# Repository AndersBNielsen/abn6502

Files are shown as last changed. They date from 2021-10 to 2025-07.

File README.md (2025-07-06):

# ABNielsen.com 6502 Single Board Computer Revision 2

This is a 6502-based complete single board computer intended to help during the global IC shortage. Why use new chips when you can reuse scrap?

## Update Update! The newest ABN6502 SBC R2 board is available as:
- Blank PCBs 
- Fully mounted PCBs including sockets and headers
- Kits with SMD components presoldered, limiting soldering to though hole components/sockets. 

All gold plated (ENIG) PCBs: https://www.imania.dk/index.php?currency=EUR&cPath=204&sort=5a&language=en

Coming soon: R2 video. 

Complete hardware overview of R1:

<a href="http://www.youtube.com/watch?feature=player_embedded&v=w5cA64xof2I" target="_blank">
 Watch the video
</a>

Video about the wireless bootloader:

<a href="http://www.youtube.com/watch?feature=player_embedded&v=NABU7gQDtcs" target="_blank">
 Watch the video
</a>

Check out the NEW project on HackADay if you want to read more and see some pretty pictures :)

https://hackaday.io/project/184725-abn6502-sbc-r1

For R1 I got rid of the Padauk MCU without increasing the chip count!

# Build instructions:

1) Send gerber files from /hardware to your favorite board house (see "Getting a PCB" below) (or get a board from [my store](https://www.imania.dk/index.php?currency=EUR&cPath=204&sort=5a&language=en)) 
2) Build the firmware using assemble.sh (macOS/Linux) - this will also try to burn the main ROM using Minipro. Dependencies: [CC65] (https://github.com/cc65/cc65) and a way to burn the ROM's.
3) Source the IC's - the spirit of this project is to contribute as little as possible to the global IC shortage and get used chips locally or from Ebay/AliExpress/etc.
4) Burn the ROMs. I use a TL866II Plus variant for the actual ROMs.
5) Solder away. If you can solder 0805 components(poorly), you should be fine. Some optional components (the microUSB connector, the 3v3 regulator, and the RF-module) require a bit more skill.  
6) For the PS/2-keyboard I use the 6522's Shift Register, PB6, and a 74xx74 flip flop.  See my R1 Hardware overview at 7:46: https://youtu.be/w5cA64xof2I?t=466 This is now included on the board - instead of a PS/2 connector which can be harder to source I went with a USB-A-connector. Keyboard plugs straight into the board. 
7) Enjoy!

Optional:
Setup SSH keys with a Raspberry Pi, connect an nRF24L01+ compatible module to it and compile the wireless bootloader code in /software_linux

Also optional:
Microsoft BASIC can be enabled by cloning the msbasic Github repo into the same folder you cloned this repo.

> git clone https://github.com/mist64/msbasic.git

Then uncomment ;BASIC := 1 (Remove the ";") and run assemble.sh - this will let you run BASIC by pressing F4.
To change settings for BASIC, values can be changed in defines_abn6502.s

Also, please note that the current code assumes VRAM starts at $0800 rather than the default $2000 in the schematic - resistors will have pads for configuring in the next build, but for now it requires jumpers.

License: Attribution-NonCommercial 4.0 International (CC BY-NC 4.0) https://creativecommons.org/licenses/by-nc/4.0/

## Getting a PCB
This project is kindly sponsored by JLCPCB. They offer cheap, professional looking PCBs and super fast delivery.

Step 1: Get the gerber file zip package from the /hardware/jlc folder
[hardware/jlcpcb/production_files/GERBER-6502.zip](hardware/jlcpcb/production_files/GERBER-6502.zip) for instance.

Step 2: Upload to JLCPCB [https://jlcpcb.com/?from=Anders_N](https://jlcpcb.com/?from=Anders_N)

Upload

Step 3: Pick your color, surface finish and order.

Select settings

Save your choice

You can use these affiliate links to get a board for $2 and also get $54 worth of New User Coupons at: https://jlcpcb.com/?from=Anders_N

And in case you also want to order a 3D-printed case you can use this link. 
How to Get a $7 3D Printing Coupon: [https://3d.jlcpcb.com/?from=Anders3DP](https://jlc3dp.com/?from=Anders_N)

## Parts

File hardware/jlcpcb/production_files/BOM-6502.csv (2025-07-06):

Comment | Designator | Footprint | LCSC | Quantity
2k2 | R14,R17,R22,R23,R24,R25 | R_0805_2012Metric | C114561 | 6
220uF | C12 | CP_Elec_6.3x7.7 | C131120 | 1
16Mhz | Y2 | Crystal_SMD_3225-4Pin_3.2x2.5mm | C13738 | 1
SST39SF010 | U5 | DIP_Socket-32_W11.9_W12.7_W15.24_W17.78_W18.5_3M_232-1285-00-0602J | C146583 | 1
100nF | C10,C11,C15,C16,C17,C18,C19,C23,C24,C25,C3,C4,C5,C6,C7,C8,C9 | C_0603_1608Metric | C14663 | 17
10uF | C22 | C_0805_2012Metric | C15850 | 1
150k | R12 | R_0805_2012Metric | C17470 | 1
150 | R7 | R_0805_2012Metric | C17471 | 1
1M | R5 | R_0805_2012Metric | C17514 | 1
3k | R1,R10,R11,R2,R3,R4,R50,R51,R52,R53,R54,R55,R56,R57,R8,R9 | R_0805_2012Metric | C17661 | 16
470 | R6 | R_0805_2012Metric | C17710 | 1
74HC14 | U1,U13,U14,U17,U21,U8 | DIP-14_W7.62mm | C2325 | 6
Interface | J20 | PinHeader_2x05_P2.54mm_Vertical | C2685204 | 1
1uF | C13,C14,C20,C21 | C_0805_2012Metric | C28323 | 4
USB2.0_16P | J9 | USB_C_Receptacle_HCTL_HC-TYPE-C-16P-01A | C2894897 | 1
5k1 | R58,R59 | R_0805_2012Metric | C3016714 | 2
MIC5504-3.3YM5 | U15 | SOT-23-5 | C3021093 | 1
Address bus | J16 | PinHeader_2x08_P2.54mm_Vertical | C30734 | 1
SW_Push | SW1 | SW_SPST_TL3342 | C318884 | 1
USB_A | J17 | USB_A_Molex_67643_Horizontal | C456018 | 1
14pF | C1,C2 | C_0805_2012Metric | C519919 | 2
DB15_Female_HighDensity | J6 | DSUB-15-HD_Female_Horizontal_P2.29x1.98mm_EdgePinOffset8.35mm_Housed_MountingHolesOffset10.89mm | C711363 | 1
74HC109 | U12,U19,U20,U6,U7 | DIP-16_W7.62mm | C72115 | 5
74HC245 | U10,U11,U4 | DIP-20_W7.62mm | C72118 | 3
62256 | U16,U18 | DIP-28_W15.24mm | C72121 | 2
R6502 | U2,U3 | DIP-40_W15.24mm | C72123 | 2
CA | J3,J4 | PinHeader_1x02_P2.54mm_Vertical | C7499322 | 2
PORTAB | J2 | PinHeader_1x16_P2.54mm_Vertical | C7500783 | 1
3v3 | 3v3,5V0,DCTRL3,DCTRL4,DCTRL5,DCTRL6,DCTRL7,DVB0,DVB1,DVEN1 | LED_0805_2012Metric | C84256 | 10
Power | J14 | PinHeader_2x06_P2.54mm_Vertical | C92269 | 1
Data_bus | J15 | PinHeader_2x04_P2.54mm_Vertical | C92271 | 1
W27c512? | J5 | PinHeader_1x02_P2.54mm_Vertical |  | 1
Control_bus | J12 | PinHeader_1x08_P2.54mm_Vertical |  | 1
GPCO | J11 | PinHeader_1x05_P2.54mm_Vertical |  | 1
16Mhz |  | Crystal_HC49-U_Vertical |  | 0
Conn_01x12_Male |  | PinHeader_1x12_P2.54mm_Vertical |  | 0
USB | J10 | PinHeader_1x02_P2.54mm_Vertical |  | 1
5V | J1 | PinHeader_1x02_P2.54mm_Vertical |  | 1
NC | R30 | SolderJumper-2_P1.3mm_Open_RoundedPad1.0x1.5mm |  | 1
5V | J8 | PinHeader_1x02_P2.54mm_Vertical |  | 1
NC |  | R_0805_2012Metric |  | 0
NC | R36 | SolderJumper-2_P1.3mm_Open_RoundedPad1.0x1.5mm |  | 1
NC | C34 | C_0805_2012Metric |  | 1
NC | R32 | SolderJumper-2_P1.3mm_Open_RoundedPad1.0x1.5mm |  | 1
NC |  | R_0805_2012Metric |  | 0
NC | C32 | C_0805_2012Metric |  | 1
NC | R31 | SolderJumper-2_P1.3mm_Open_RoundedPad1.0x1.5mm |  | 1
NC | R39 | SolderJumper-2_P1.3mm_Open_RoundedPad1.0x1.5mm |  | 1
NC | C29 | C_0805_2012Metric |  | 1
NC | R49 | R_0805_2012Metric |  | 1
NC | C30 | C_0805_2012Metric |  | 1
NC | R44 | SolderJumper-2_P1.3mm_Open_RoundedPad1.0x1.5mm |  | 1
NC | C27 | C_0805_2012Metric |  | 1
NRF24L01_Breakout | U9 | NRF24L01-SMD |  | 1
NC | C33 | C_0805_2012Metric |  | 1
NC |  | R_0805_2012Metric |  | 0
NC | C28 | C_0805_2012Metric |  | 1
NC | R34 | SolderJumper-2_P1.3mm_Open_RoundedPad1.0x1.5mm |  | 1
NC | R29 | SolderJumper-2_P1.3mm_Open_RoundedPad1.0x1.5mm |  | 1
NC | R47 | SolderJumper-2_P1.3mm_Open_RoundedPad1.0x1.5mm |  | 1
NC | R33 | SolderJumper-2_P1.3mm_Open_RoundedPad1.0x1.5mm |  | 1
NC | R37 | SolderJumper-2_P1.3mm_Open_RoundedPad1.0x1.5mm |  | 1
NC | R43 | SolderJumper-2_P1.3mm_Open_RoundedPad1.0x1.5mm |  | 1
NC |  | R_0805_2012Metric |  | 0
NC | R35 | SolderJumper-2_P1.3mm_Open_RoundedPad1.0x1.5mm |  | 1
NC | C35 | C_0805_2012Metric |  | 1
NC | R45 | SolderJumper-2_P1.3mm_Open_RoundedPad1.0x1.5mm |  | 1
NC | C31 | C_0805_2012Metric |  | 1
NC | R42 | SolderJumper-2_P1.3mm_Open_RoundedPad1.0x1.5mm |  | 1
NC | R46 | SolderJumper-2_P1.3mm_Open_RoundedPad1.0x1.5mm |  | 1
NC | C36 | C_0805_2012Metric |  | 1
NC | R38 | SolderJumper-2_P1.3mm_Open_RoundedPad1.0x1.5mm |  | 1
NC | C37 | C_0805_2012Metric |  | 1
NC | R41 | SolderJumper-2_P1.3mm_Open_RoundedPad1.0x1.5mm |  | 1
NC | C26 | C_0805_2012Metric |  | 1
NC | R40 | SolderJumper-2_P1.3mm_Open_RoundedPad1.0x1.5mm |  | 1

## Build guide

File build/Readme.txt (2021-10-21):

This folder is where the build output goes for ROMs

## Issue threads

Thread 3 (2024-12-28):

Questions About VGA - Custom Build Help

vslinuxdotnet, 2024-12-28:
Hello dear Anders,

I build this board in dev PCB board but no output video was displayed in my old LCD.
The board seams working e have first debug led ON means CE in 74ls165 LOW, so chip IC enable correct ?
I have VSYNC (36Hz+-) and HSYNC (51Hz+-) signals not very stable, Green about 2Mhz wave form, is ok ?
You say in video the resolution is 512x512, this will only work in old CRT or can also work with old year 2000 small LCD ?
What test can i do the check if the board in not freezed ?

Thank You,

VS

AndersBNielsen, 2024-12-28:
Do you have the VRAM configured on the back of the board and does it match
the address defined in code?
The resolution is a bit odd - 400x240 and you can’t be sure the monitor
will register that.
If you have a modern monitor it should register it as 800x480 - if you have
an older flat panel you might need to crop in software to 640x480 (just
don’t write to edges of the screen framebuffer).

Do *not* connect a CRT unless you have verified yourself that it’s safe for
your CRT (I wouldn’t recommend it)

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

vslinuxdotnet, 2024-12-28:
I have the resistors configured like your diagram, what is the address $4000 ?
the resistors that change that is R18,R19,R20,R21 ?
1=HIGH,0=LOW, so 1000 = $4000
Can explain a like more :) ?
In your code:
SCREENSTARTH = $08 ; Change this to the page your Video RAM starts! (VRAM at $0800 requires a few jumpers to change from the default $2000 - this will change in the next build of R1)

So i have it in wrong address ?

> Do you have the VRAM configured on the back of the board and does it match the address defined in code? The resolution is a bit odd - 400x240 and you can’t be sure the monitor will register that. If you have a modern monitor it should register it as 800x480 - if you have an older flat panel you might need to crop in software to 640x480 (just don’t write to edges of the screen framebuffer). Do *not* connect a CRT unless you have verified yourself that it’s safe for your CRT (I wouldn’t recommend it)
> […](#)
> On Sat, Dec 28, 2024 at 20.17 Vasco Santos ***@***.***> wrote: Hello dear Anders, I build this board in dev PCB board but no output video was displayed in my old LCD. The board seams working e have first debug led ON means CE in 74ls165 LOW, so chip IC enable correct ? I have VSYNC (37Hz+-) and HSYNC (60Hz+-) signals, Green about 2Mhz wave form, is ok ? You say in video the resolution is 512x512, this will only work in old CRT or can also work with old year 2000 small LCD ? What test can I do the check if the board in not freezed or something like that. Thank You, VS — Reply to this email directly, view it on GitHub <#3>, or unsubscribe <https://github.com/notifications/unsubscribe-auth/AB2SHITVAITFTI2MB2IQIR32H3TK3AVCNFSM6AAAAABUKALTVKVHI2DSMVQWIX3LMV43ASLTON2WKOZSG43DCOBSGQ2DMMQ> . You are receiving this because you are subscribed to this thread.Message ID: ***@***.***>

vslinuxdotnet, 2024-12-29:
No luck to get it working, check all IC's checked wires and no luck, must debug it by serial or a led blink.
I found a interesting thing about the 74hc04A that pass from 10ma to 60ma, and get gets hot or more just by touch in pins.

The beast:

vslinuxdotnet, 2025-01-03:
Sorry for bothering you about this, but can you help ?
Thanks

AndersBNielsen, 2025-01-04:
Absolutely! I haven’t had too much time over the holidays but that should
change soon.

I found a bug that the 74’161 must be a 74LS161 and not a 74HC161 - not
sure if that could be affecting you?

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

vslinuxdotnet, 2025-01-04:
Hello, thanks for your time.
I have the LS version but I order the HC version :).
The problem is that I don't have the correct Vsync and Hsync, which seems Random at 30khz.
What is the correct value to put in VRam register?
In past two days in debug, meter wires and corrections with an oscilloscope and the board is alive all wires ok just no vga.
I also simulate with a Arduino to create the 60khz and 31.5khz and the monitor turns on without image.

Note: if you put some A17 jumper option to GND, and connect reset you will support more ROMS :)

A 4 de janeiro de 2025 07:44:12 WET, AndersBNielsen ***@***.***> escreveu:
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
--
Sent from my Android device with K-9 Mail. Please excuse my brevity.

AndersBNielsen, 2025-01-04:
Sounds like you have the correct VRAM resistors.
Regardless you should have a stable VSYNC and HSYNC - that part only relies
on the ‘590s and the bit of glue logic generating the syncs.
I suggest you check the inputs of the ‘109 JnK and if you don’t see
something reasonable trace back towards the 590s.

Another thing - Did you populate the reset circuit on the back?

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

vslinuxdotnet, 2025-01-04:
This circuit can generate Vsync and Hsync without CPU and ROM?
What is the correct VRAM address for the default resistors in your diagram?

A 4 de janeiro de 2025 09:23:18 WET, AndersBNielsen ***@***.***> escreveu:
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
--
Sent from my Android device with K-9 Mail. Please excuse my brevity.

AndersBNielsen, 2025-01-04:
The way it is in the schematic with only A11 pulled high and A12-14 pulled
low puts the VRAM base address at $0800

If the counters and U8, U17 and U12 are functioning correctly, you should
have sync signals.

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

vslinuxdotnet, 2025-01-04:
Ok, that's it, the counters without CPU, Ram or ROM will get the sync?

A 4 de janeiro de 2025 12:26:31 WET, AndersBNielsen ***@***.***> escreveu:
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
--
Sent from my Android device with K-9 Mail. Please excuse my brevity.

AndersBNielsen, 2025-01-04:
Yup. The counters just need the 2MHz from the ‘161.
It might be hard to get it going without a PCB though.

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

vslinuxdotnet, 2025-01-09:
Hello,
after some debug about 74hc590... I Detected  fakes IC's!
I tested the logic and works with low speed clock, but with 1Mhz or so they get completely malfunction, stops counting, reset it self.
I order new old stock arrived today and get some vsync and hsync finally!
But not the 31.5khz and 60.0khz needed, I get 31.25khz and 60.15khz, it's close... but not the correct frequency to turn on the screen.
I replace the 74hc109 and the 74hc32, tested with a 12mhz oscillator but get the same clock with this minimal error.
What can I do ?

Thanks

AndersBNielsen, 2025-01-10:
60Hz you mean :)

31.25KHz is less than 0.8% off - that should work. It could be it doesn't want to turn on because of random data on the rgb lines - you can try pulling RGB low instead of connecting them.

vslinuxdotnet, 2025-01-11:
Hello,
yes it 60Hz, any the SYNC error is acceptable, after some debug is finally working!!!
The main problem was the fakes 74hc590p.
This ones :
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

Then i tested in my 19" CRT with 25 years and don't work because R and B must be to GND or no picture available and not turn on.
But  in LCD's they don't care about R and B lines disconnected, they will turn on just with sync lines.

So if you what some considerations to do in your next revision:

  - U19 and U20 must be LS version or they don't work as expected.
  - U14 is recommended to be HCT version, with HC version, they can suck 200mA, gets hot and died at random time.
  - Red and Blue must be connected to GND or  some CRT's from the past may not work.
  - To support more Flash ROM's add a jumper to pin 30 to GND and pin 1 connect it to main RST.

Many thanks for your time.
Regards.

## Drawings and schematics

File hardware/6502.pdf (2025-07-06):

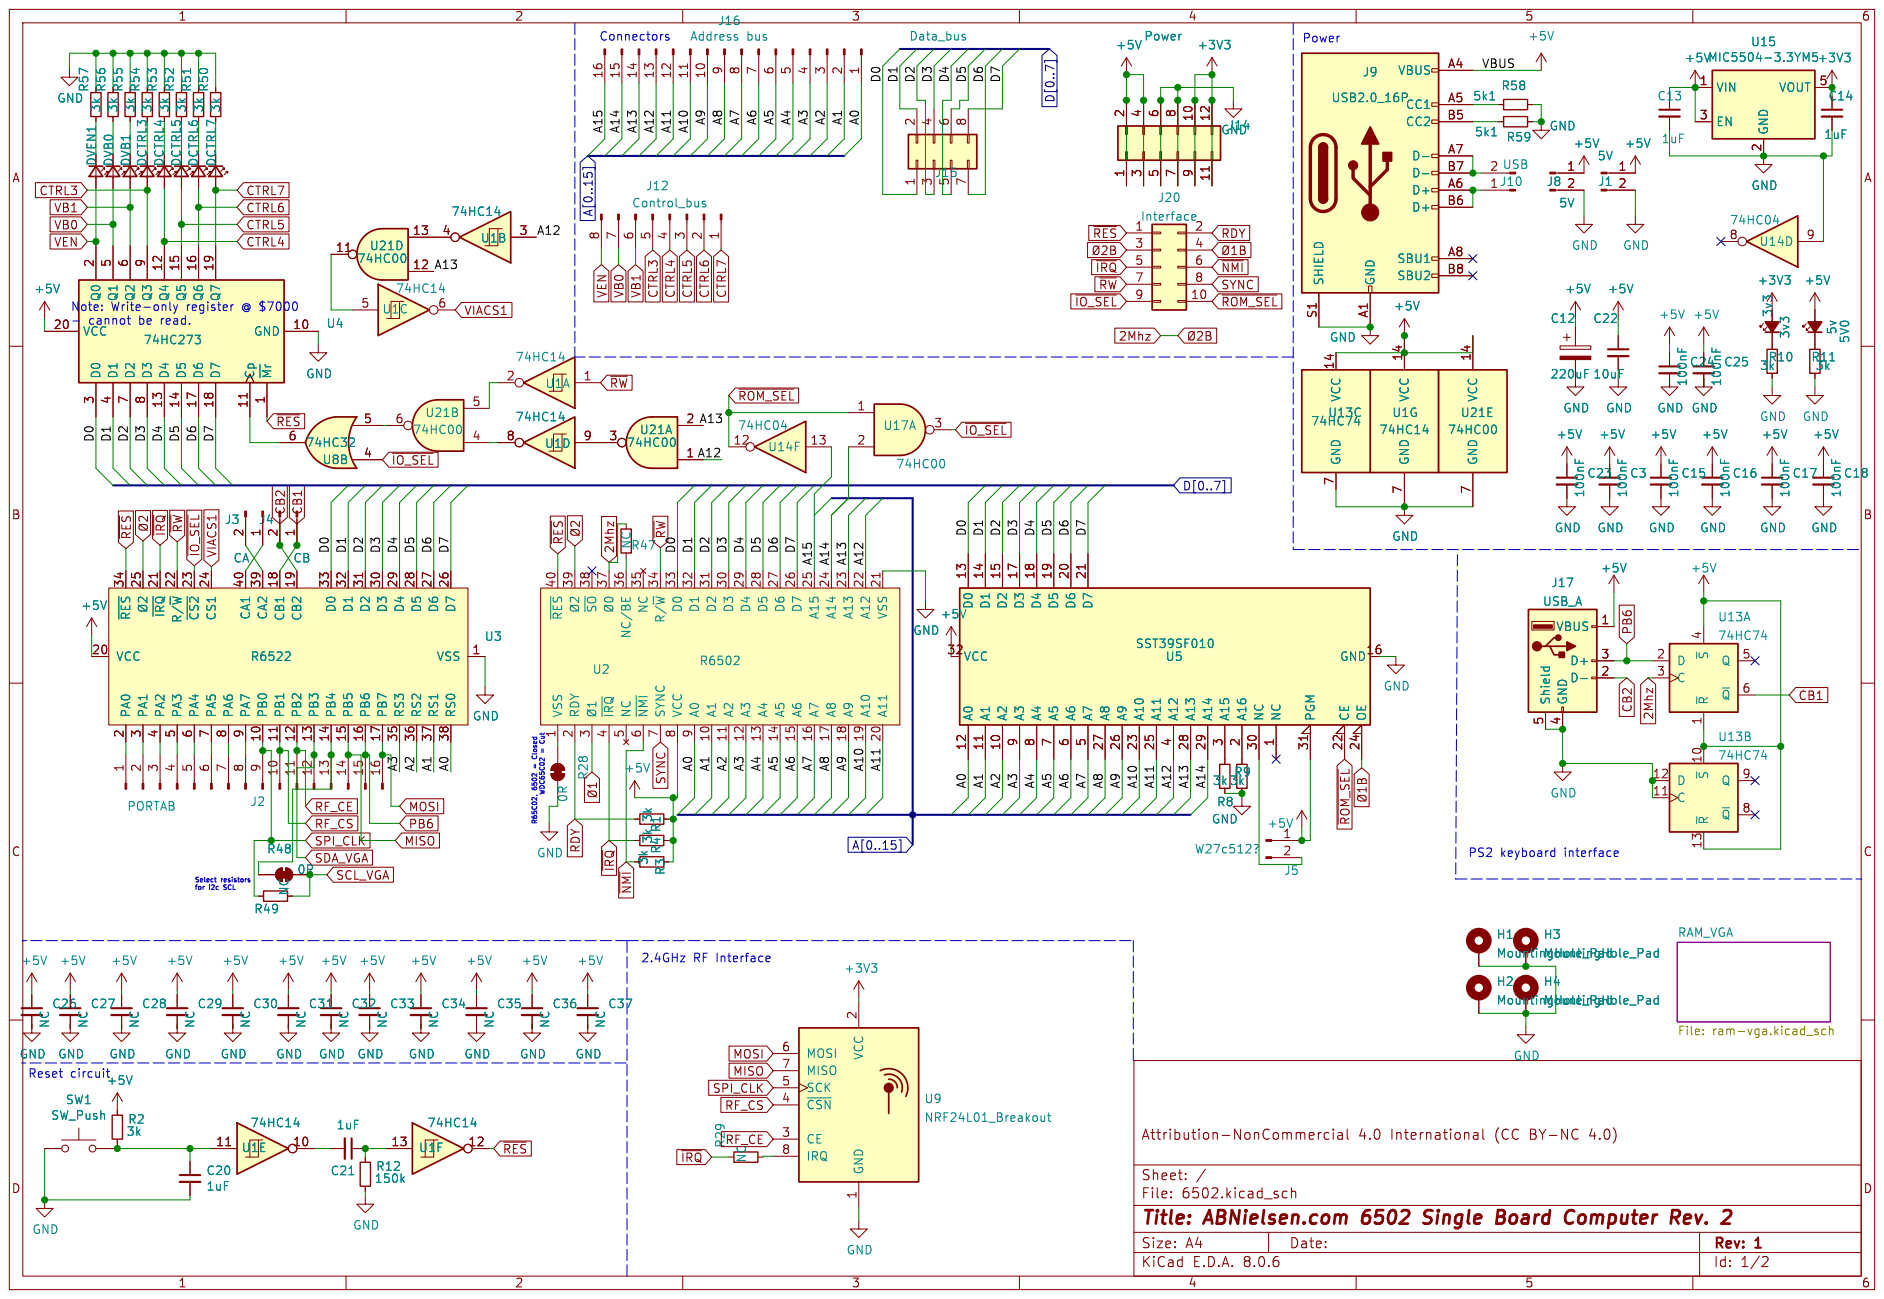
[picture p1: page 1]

3 D3 30 D2 31 D1 32 D0 33 R/~{W}34 NC 35 NC/BE 36 þÿØ037 ~{SO}38 þÿØ239 ~{IRQ} 4 ~{RES}40 NC

File: ram-vga.kicad_sch C28 NC

2 CE 3 ~{CSN} 4 SCK 5 MOSI 6 MISO 7

Id: 1/2 Title: ABNielsen.com 6502 Single Board Computer Rev. 2

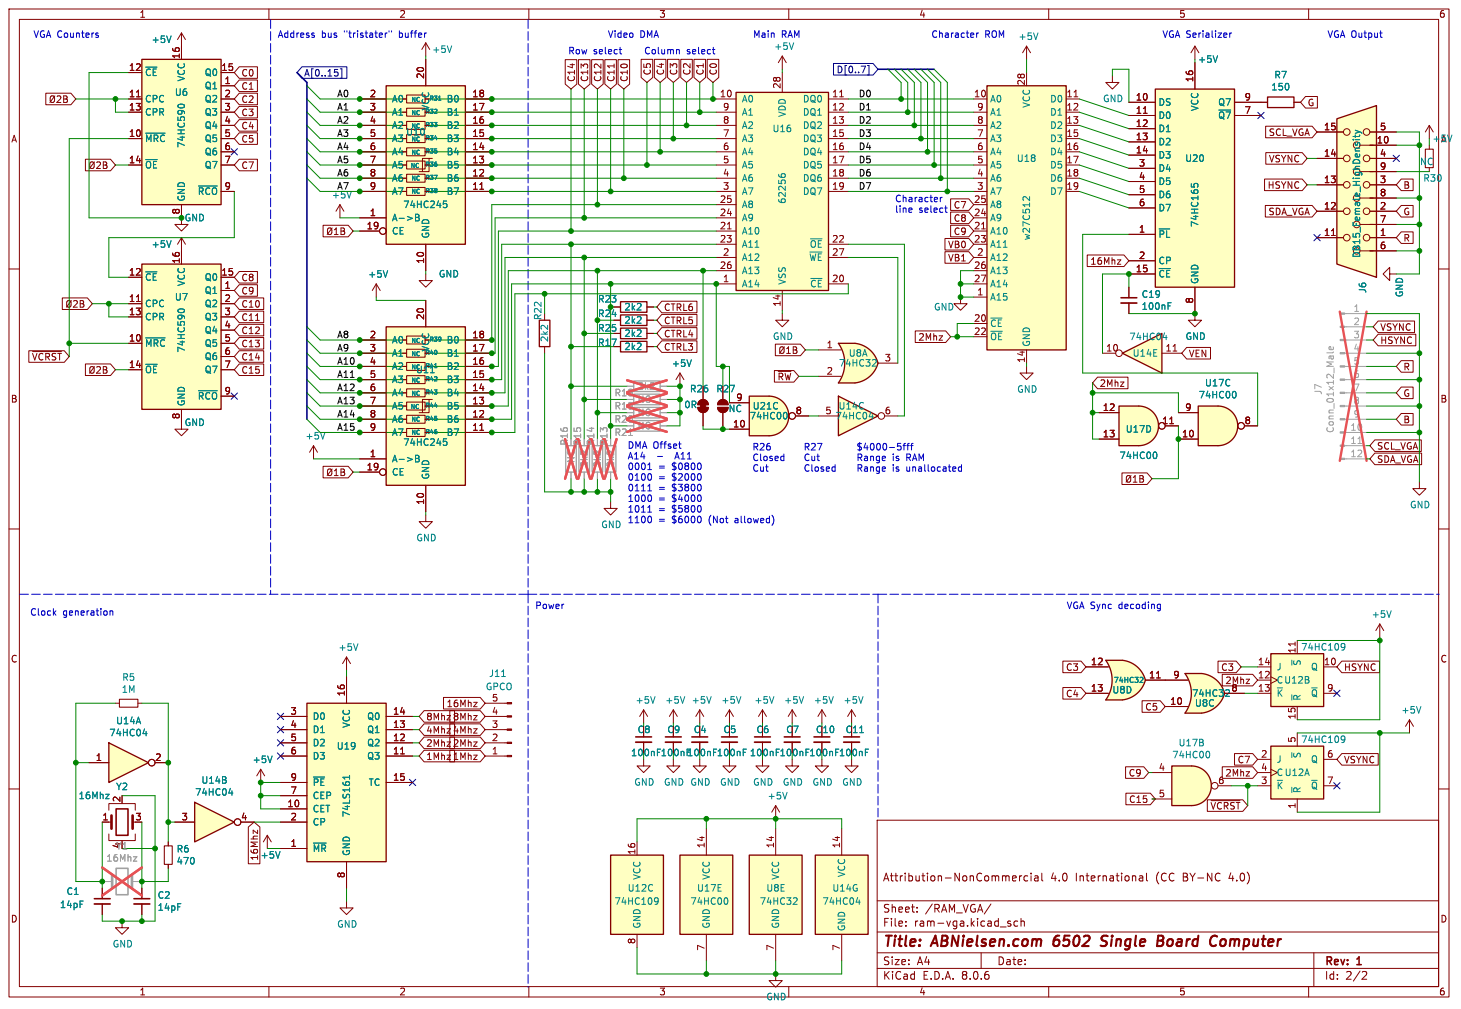
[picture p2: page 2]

1100 = $6000 (Not allowed) Main RAM
+5V VCC 14 GND
Column select Power

8 ~{RCO}9 U674HC590 A->B 1 GND 10 B7 11 B6 12 B5 13 B4 14 B3 15 B2 16 B1 17 B0 18 CE 19 A0 2 VCC 20 A1 3 A2 4 A3 5 A4 6 A5 7 A6 8 A7 9 U10

GND GND GND VCC 14 GND

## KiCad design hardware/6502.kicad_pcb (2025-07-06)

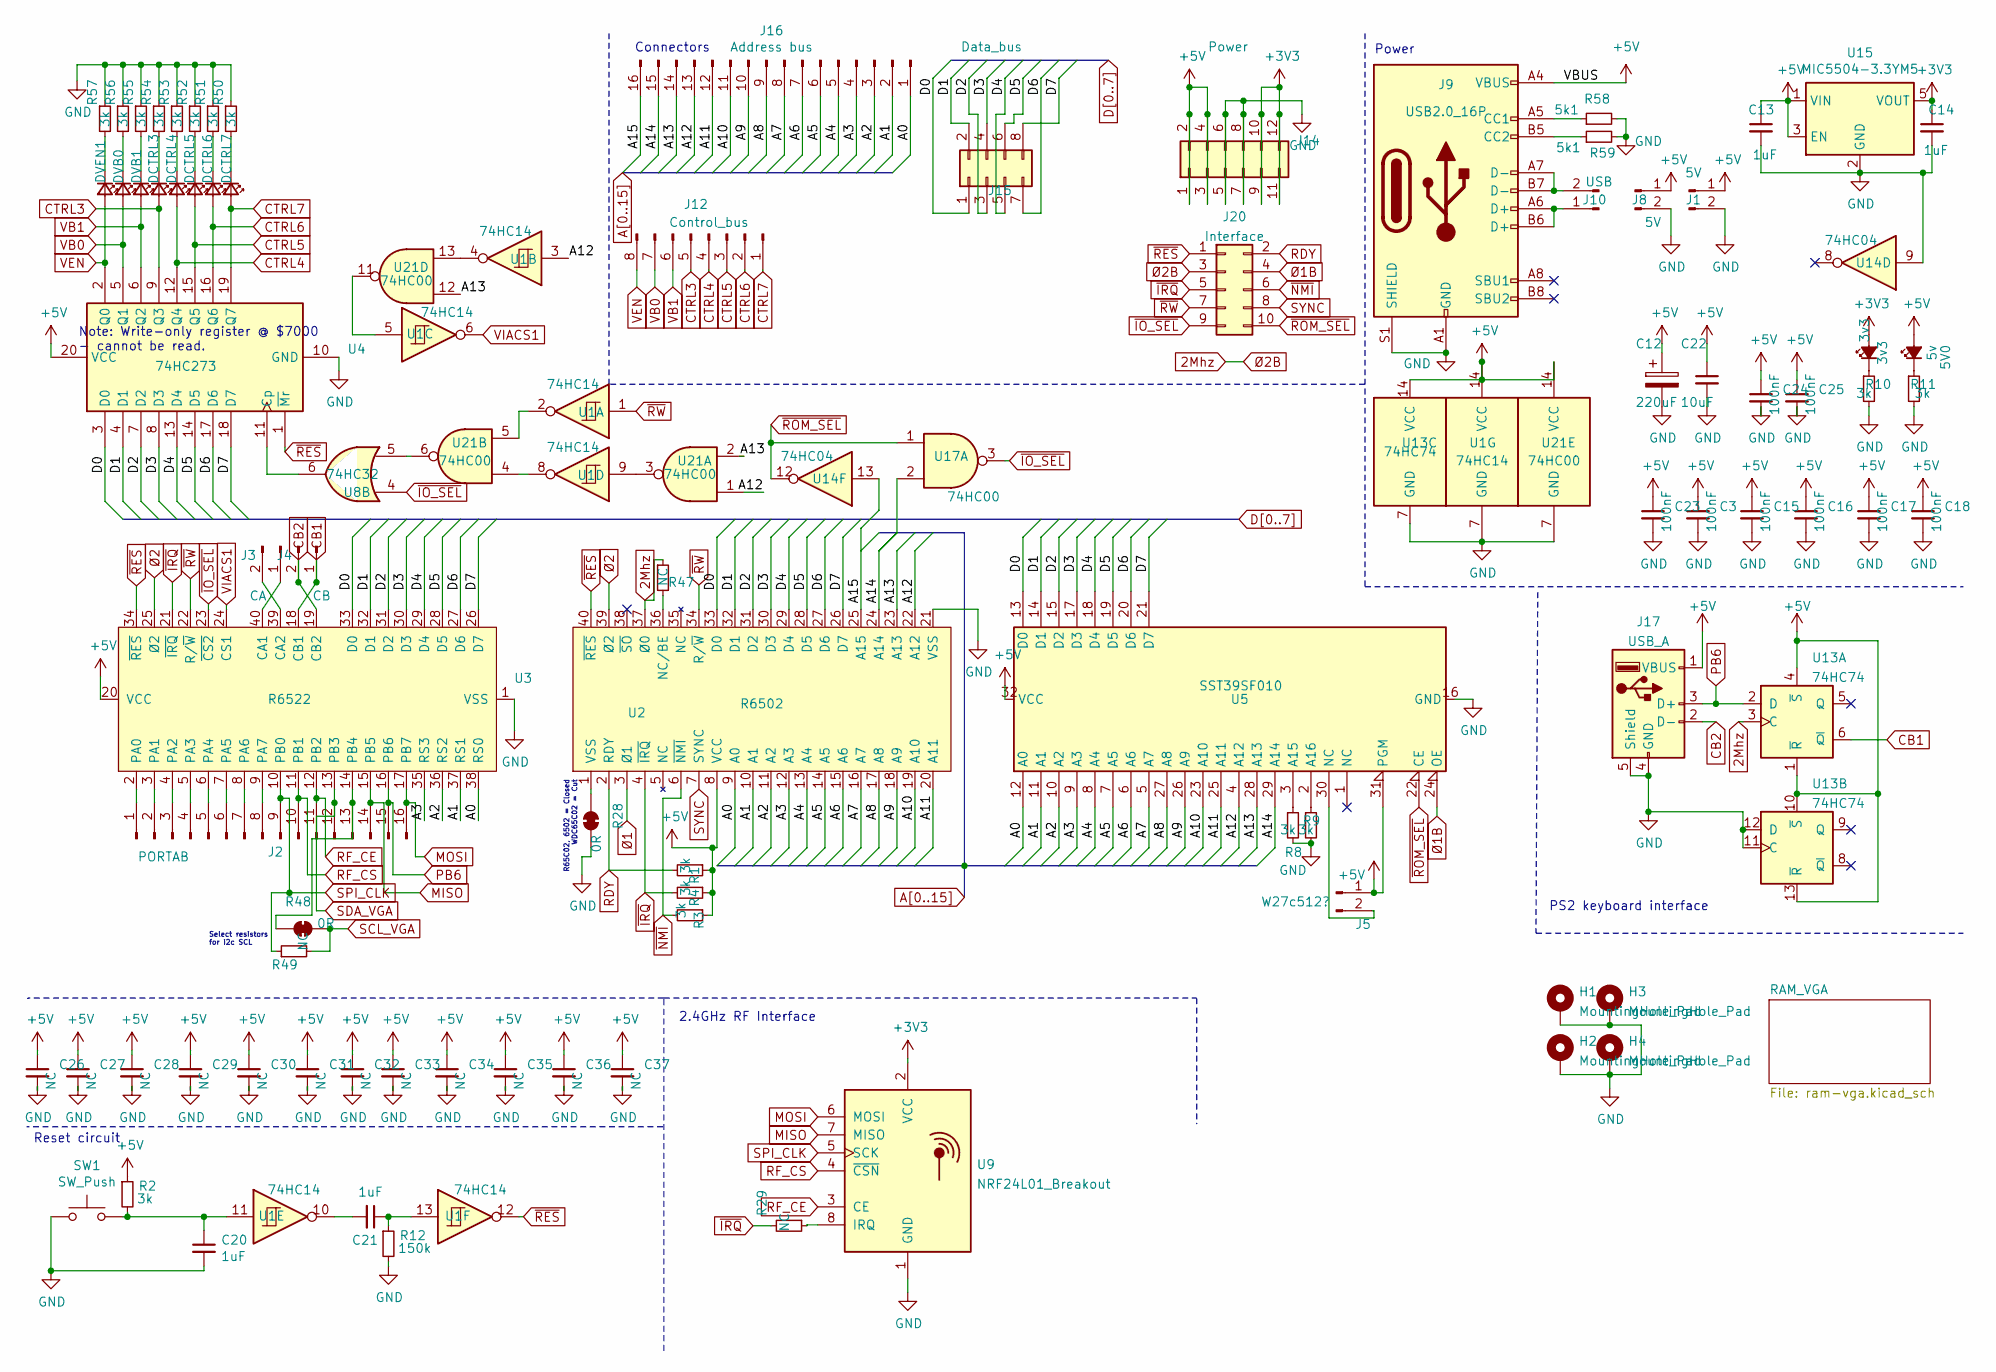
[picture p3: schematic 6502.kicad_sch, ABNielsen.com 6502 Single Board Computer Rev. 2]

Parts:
3v3: 3v3; LED_0805_2012Metric; LCSC C84256
5V0: 5v; LED_0805_2012Metric; LCSC C84256
C3, C15, C16, C17, C18, C23, C24, C25: 100nF; C_0603_1608Metric; LCSC C14663
C12: 220uF; CP_Elec_6.3x7.7; LCSC C131120
C13, C14, C20, C21: 1uF; C_0805_2012Metric; LCSC C28323
C22: 10uF; C_0805_2012Metric
C26, C27, C28, C29, C30, C31, C32, C33, C34, C35, C36, C37: NC; C_0805_2012Metric
DCTRL3, DCTRL4, DCTRL5, DCTRL6, DCTRL7: RED; LED_0805_2012Metric; LCSC C84256
DVB0, DVB1: RED; LED_0805_2012Metric; LCSC C84256
DVEN1: RED; LED_0805_2012Metric; LCSC C84256
H1, H2, H3, H4: MountingHole_Pad; MountingHole_4.3mm_M4_ISO14580_Pad
J1, J8: 5V; PinHeader_1x02_P2.54mm_Vertical
J2: PORTAB; PinHeader_1x16_P2.54mm_Vertical; LCSC C7500783
J3: CA; PinHeader_1x02_P2.54mm_Vertical; LCSC C7499322
J4: CB; PinHeader_1x02_P2.54mm_Vertical; LCSC C7499322
J5: W27c512?; PinHeader_1x02_P2.54mm_Vertical
J9: USB2.0_16P; USB_C_Receptacle_HCTL_HC-TYPE-C-16P-01A; LCSC C2894897
J10: USB; PinHeader_1x02_P2.54mm_Vertical
J12: Control_bus; PinHeader_1x08_P2.54mm_Vertical
J14: Power; PinHeader_2x06_P2.54mm_Vertical; LCSC C92269
J15: Data_bus; PinHeader_2x04_P2.54mm_Vertical; LCSC C92271
J16: Address bus; PinHeader_2x08_P2.54mm_Vertical; LCSC C30734
J17: USB_A; USB_A_Molex_67643_Horizontal; LCSC C456018
J20: Interface; PinHeader_2x05_P2.54mm_Vertical; LCSC C2685204
R1, R2, R3, R4, R8, R9, R10, R11, R50, R51, R52, R53, R54, R55, R56, R57: 3k; R_0805_2012Metric; LCSC C17661
R12: 150k; R_0805_2012Metric; LCSC C17470
R28, R48: 0R; SolderJumper-2_P1.3mm_Bridged_RoundedPad1.0x1.5mm
R29, R47: NC; SolderJumper-2_P1.3mm_Open_RoundedPad1.0x1.5mm
R49: NC; R_0805_2012Metric
R58, R59: 5k1; R_0805_2012Metric; LCSC C3016714
SW1: SW_Push; SW_SPST_TL3342; LCSC C318884
U1: 74HC14; DIP-14_W7.62mm; LCSC C2325
U2: R6502; DIP-40_W15.24mm; LCSC C72123
U3: R6522; DIP-40_W15.24mm; LCSC C72123
U4: 74HC273; DIP-20_W7.62mm; LCSC C72118
U5: SST39SF010; DIP_Socket-32_W11.9_W12.7_W15.24_W17.78_W18.5_3M_232-1285-0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; LCSC C146583
U8: 74HC32; DIP-14_W7.62mm; LCSC C2325
U9: NRF24L01_Breakout; NRF24L01-SMD
U13: 74HC74; DIP-14_W7.62mm; LCSC C2325
U14: 74HC04; DIP-14_W7.62mm; LCSC C2325
U15: MIC5504-3.3YM5; SOT-23-5; LCSC C3021093
U17, U21: 74HC00; DIP-14_W7.62mm; LCSC C2325

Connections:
2Mhz: J20.3, R47.1, U2.37 (Ø0), U13.3 (C); also elsewhere on the board
+3V3: 3v3.2 (A), C14.1, J14.9, J14.10, J14.11, J14.12, U9.2 (VCC), U15.5 (VOUT)
+5V: 5V0.2 (A), C3.1, C12.1, C13.1, C15.1, C16.1, C17.1, C18.1, C22.1, C23.1, C24.1, C25.1, C26.1, C27.1, C28.1, C29.1, C30.1, C31.1, C32.1, C33.1, C34.1, C35.1, C36.1, C37.1, J1.1, J5.1, J8.1, J9.A4 (VBUS), J9.A9 (VBUS), J9.B4 (VBUS), J9.B9 (VBUS), J14.1, J14.2, J14.3, J14.4, J17.1 (VBUS), R1.1, R2.1, R3.1, R4.1, U1.14 (VCC), U2.8 (VCC), U3.20 (VCC), U4.20 (VCC), U5.31 (PGM), U5.32 (VCC), U13.1 (~R), U13.4 (~S), U13.10 (~S), U13.13 (~R), U13.14 (VCC), U15.1 (VIN), U15.3 (EN), U21.14 (VCC); also elsewhere on the board
A0: J16.1, U2.9 (A0), U3.38 (RS0), U5.12 (A0); also elsewhere on the board
A1: J16.2, U2.10 (A1), U3.37 (RS1), U5.11 (A1); also elsewhere on the board
A2: J16.3, U2.11 (A2), U3.36 (RS2), U5.10 (A2); also elsewhere on the board
A3: J16.4, U2.12 (A3), U3.35 (RS3), U5.9 (A3); also elsewhere on the board
A4: J16.5, U2.13 (A4), U5.8 (A4); also elsewhere on the board
A5: J16.6, U2.14 (A5), U5.7 (A5); also elsewhere on the board
A6: J16.7, U2.15 (A6), U5.6 (A6); also elsewhere on the board
A7: J16.8, U2.16 (A7), U5.5 (A7); also elsewhere on the board
A8: J16.9, U2.17 (A8), U5.27 (A8); also elsewhere on the board
A9: J16.10, U2.18 (A9), U5.26 (A9); also elsewhere on the board
A10: J16.11, U2.19 (A10), U5.23 (A10); also elsewhere on the board
A11: J16.12, U2.20 (A11), U5.25 (A11); also elsewhere on the board
A12: J16.13, U1.3, U2.22 (A12), U5.4 (A12), U21.1; also elsewhere on the board
A13: J16.14, U2.23 (A13), U5.28 (A13), U21.2, U21.12; also elsewhere on the board
A14: J16.15, U2.24 (A14), U5.29 (A14), U17.2; also elsewhere on the board
A15: J16.16, U2.25 (A15), U14.13; also elsewhere on the board
CB1: J4.1, U3.18 (CB1), U13.6 (~Q)
CB2: J4.2, J17.2 (D-), U3.19 (CB2)
CTRL3: DCTRL3.2 (A), J12.5, U4.9 (Q3); also elsewhere on the board
CTRL4: DCTRL4.2 (A), J12.4, U4.12 (Q4); also elsewhere on the board
CTRL5: DCTRL5.2 (A), J12.3, U4.15 (Q5); also elsewhere on the board
CTRL6: DCTRL6.2 (A), J12.2, U4.16 (Q6); also elsewhere on the board
CTRL7: DCTRL7.2 (A), J12.1, U4.19 (Q7)
D0: J15.1, U2.33 (D0), U3.33 (D0), U4.3 (D0), U5.13 (D0); also elsewhere on the board
D1: J15.2, U2.32 (D1), U3.32 (D1), U4.4 (D1), U5.14 (D1); also elsewhere on the board
D2: J15.3, U2.31 (D2), U3.31 (D2), U4.7 (D2), U5.15 (D2); also elsewhere on the board
D3: J15.4, U2.30 (D3), U3.30 (D3), U4.8 (D3), U5.17 (D3); also elsewhere on the board
D4: J15.5, U2.29 (D4), U3.29 (D4), U4.13 (D4), U5.18 (D4); also elsewhere on the board
D5: J15.6, U2.28 (D5), U3.28 (D5), U4.14 (D5), U5.19 (D5); also elsewhere on the board
D6: J15.7, U2.27 (D6), U3.27 (D6), U4.17 (D6), U5.20 (D6); also elsewhere on the board
D7: J15.8, U2.26 (D7), U3.26 (D7), U4.18 (D7), U5.21 (D7); also elsewhere on the board
GND: C3.2, C12.2, C13.2, C14.2, C15.2, C16.2, C17.2, C18.2, C20.2, C22.2, C23.2, C24.2, C25.2, C26.2, C27.2, C28.2, C29.2, C30.2, C31.2, C32.2, C33.2, C34.2, C35.2, C36.2, C37.2, H1.1, H2.1, H3.1, H4.1, J1.2, J8.2, J9.A1 (GND), J9.A12 (GND), J9.B1 (GND), J9.B12 (GND), J9.S1 (SHIELD), J14.5, J14.6, J14.7, J14.8, J17.4 (GND), J17.5 (Shield), R8.2, R9.2, R10.2, R11.2, R12.2, R28.1 (A), R50.1, R51.1, R52.1, R53.1, R54.1, R55.1, R56.1, R57.1, R58.2, R59.2, SW1.1, U1.7 (GND), U2.21 (VSS), U3.1 (VSS), U4.10 (GND), U5.16 (GND), U9.1 (GND), U13.7 (GND), U13.11 (C), U13.12 (D), U14.9, U15.2 (GND), U21.7 (GND); also elsewhere on the board
MISO: J2.14, U3.15 (PB5), U9.7 (MISO)
MOSI: J2.16, U3.17 (PB7), U9.6 (MOSI)
unnamed: 3v3.1 (K), R10.1
unnamed: 5V0.1 (K), R11.1
unnamed: C20.1, R2.2, SW1.2, U1.11
unnamed: C21.1, R12.1, U1.13
unnamed: C21.2, U1.10
unnamed: DCTRL3.1 (K), R54.2
unnamed: DCTRL4.1 (K), R53.2
unnamed: DCTRL5.1 (K), R52.2
unnamed: DCTRL6.1 (K), R51.2
unnamed: DCTRL7.1 (K), R50.2
unnamed: DVB0.1 (K), R56.2
unnamed: DVB1.1 (K), R55.2
unnamed: DVEN1.1 (K), R57.2
unnamed: J2.1, U3.2 (PA0)
unnamed: J2.2, U3.3 (PA1)
unnamed: J2.3, U3.4 (PA2)
unnamed: J2.4, U3.5 (PA3)
unnamed: J2.5, U3.6 (PA4)
unnamed: J2.6, U3.7 (PA5)
unnamed: J2.7, U3.8 (PA6)
unnamed: J2.8, U3.9 (PA7)
unnamed: J2.13, R48.2 (B), U3.14 (PB4)
unnamed: J3.1, U3.40 (CA1)
unnamed: J3.2, U3.39 (CA2)
unnamed: J5.2, U5.30 (NC)
unnamed: J9.A5 (CC1), R58.1
unnamed: J9.B5 (CC2), R59.1
unnamed: J9.A6 (D+), J9.B6 (D+), J10.1
unnamed: J9.A7 (D-), J9.B7 (D-), J10.2
unnamed: R28.2 (B), U2.1 (VSS)
unnamed: U1.2, U21.5
unnamed: U1.4, U21.13
unnamed: U1.5, U21.11
unnamed: U1.8, U21.4
unnamed: U1.9, U21.3
unnamed: R47.2, U2.36 (NC/BE)
unnamed: U4.11 (Cp), U8.6
unnamed: R8.1, U5.3 (A15)
unnamed: R9.1, U5.2 (A16)
unnamed: R29.1, U9.8 (IRQ)
unnamed: U8.5, U21.6
PB6: J2.15, J17.3 (D+), U3.16 (PB6), U13.2 (D)
RDY: J20.2, R1.2, U2.2 (RDY)
RF_CE: J2.11, U3.12 (PB2), U9.3 (CE)
RF_CS: J2.10, U3.11 (PB1), U9.4 (~CSN)
SCL_VGA: R48.1 (A), R49.2; also elsewhere on the board
SDA_VGA: J2.12, U3.13 (PB3); also elsewhere on the board
SPI_CLK: J2.9, R49.1, U3.10 (PB0), U9.5 (SCK)
SYNC: J20.8, U2.7 (SYNC)
VB0: DVB0.2 (A), J12.7, U4.5 (Q1); also elsewhere on the board
VB1: DVB1.2 (A), J12.6, U4.6 (Q2); also elsewhere on the board
VEN: DVEN1.2 (A), J12.8, U4.2 (Q0); also elsewhere on the board
VIACS1: U1.6, U3.24 (CS1)
~IO_SEL: J20.9, U3.23 (~CS2), U8.4, U17.3
~IRQ: J20.5, R4.2, R29.2, U2.4 (~IRQ), U3.21 (~IRQ)
~NMI: J20.6, R3.2, U2.6 (~NMI)
~RES: J20.1, U1.12, U2.40 (~RES), U3.34 (~RES), U4.1 (~Mr)
~ROM_SEL: J20.10, U5.22 (CE), U14.12, U17.1
~RW: J20.7, U1.1, U2.34 (R/~W), U3.22 (R/~W); also elsewhere on the board
Ø1: U2.3 (Ø1)
Ø1B: J20.4, U5.24 (OE); also elsewhere on the board
Ø2: U2.39 (Ø2), U3.25 (Ø2)

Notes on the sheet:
Note: Write-only register @ $7000 - cannot be read.
Select resistors for i2c SCL
Power
R65C02, 6502 = Closed WDC65C02 = Cut
Reset circuit
Connectors
PS2 keyboard interface
2.4GHz RF Interface

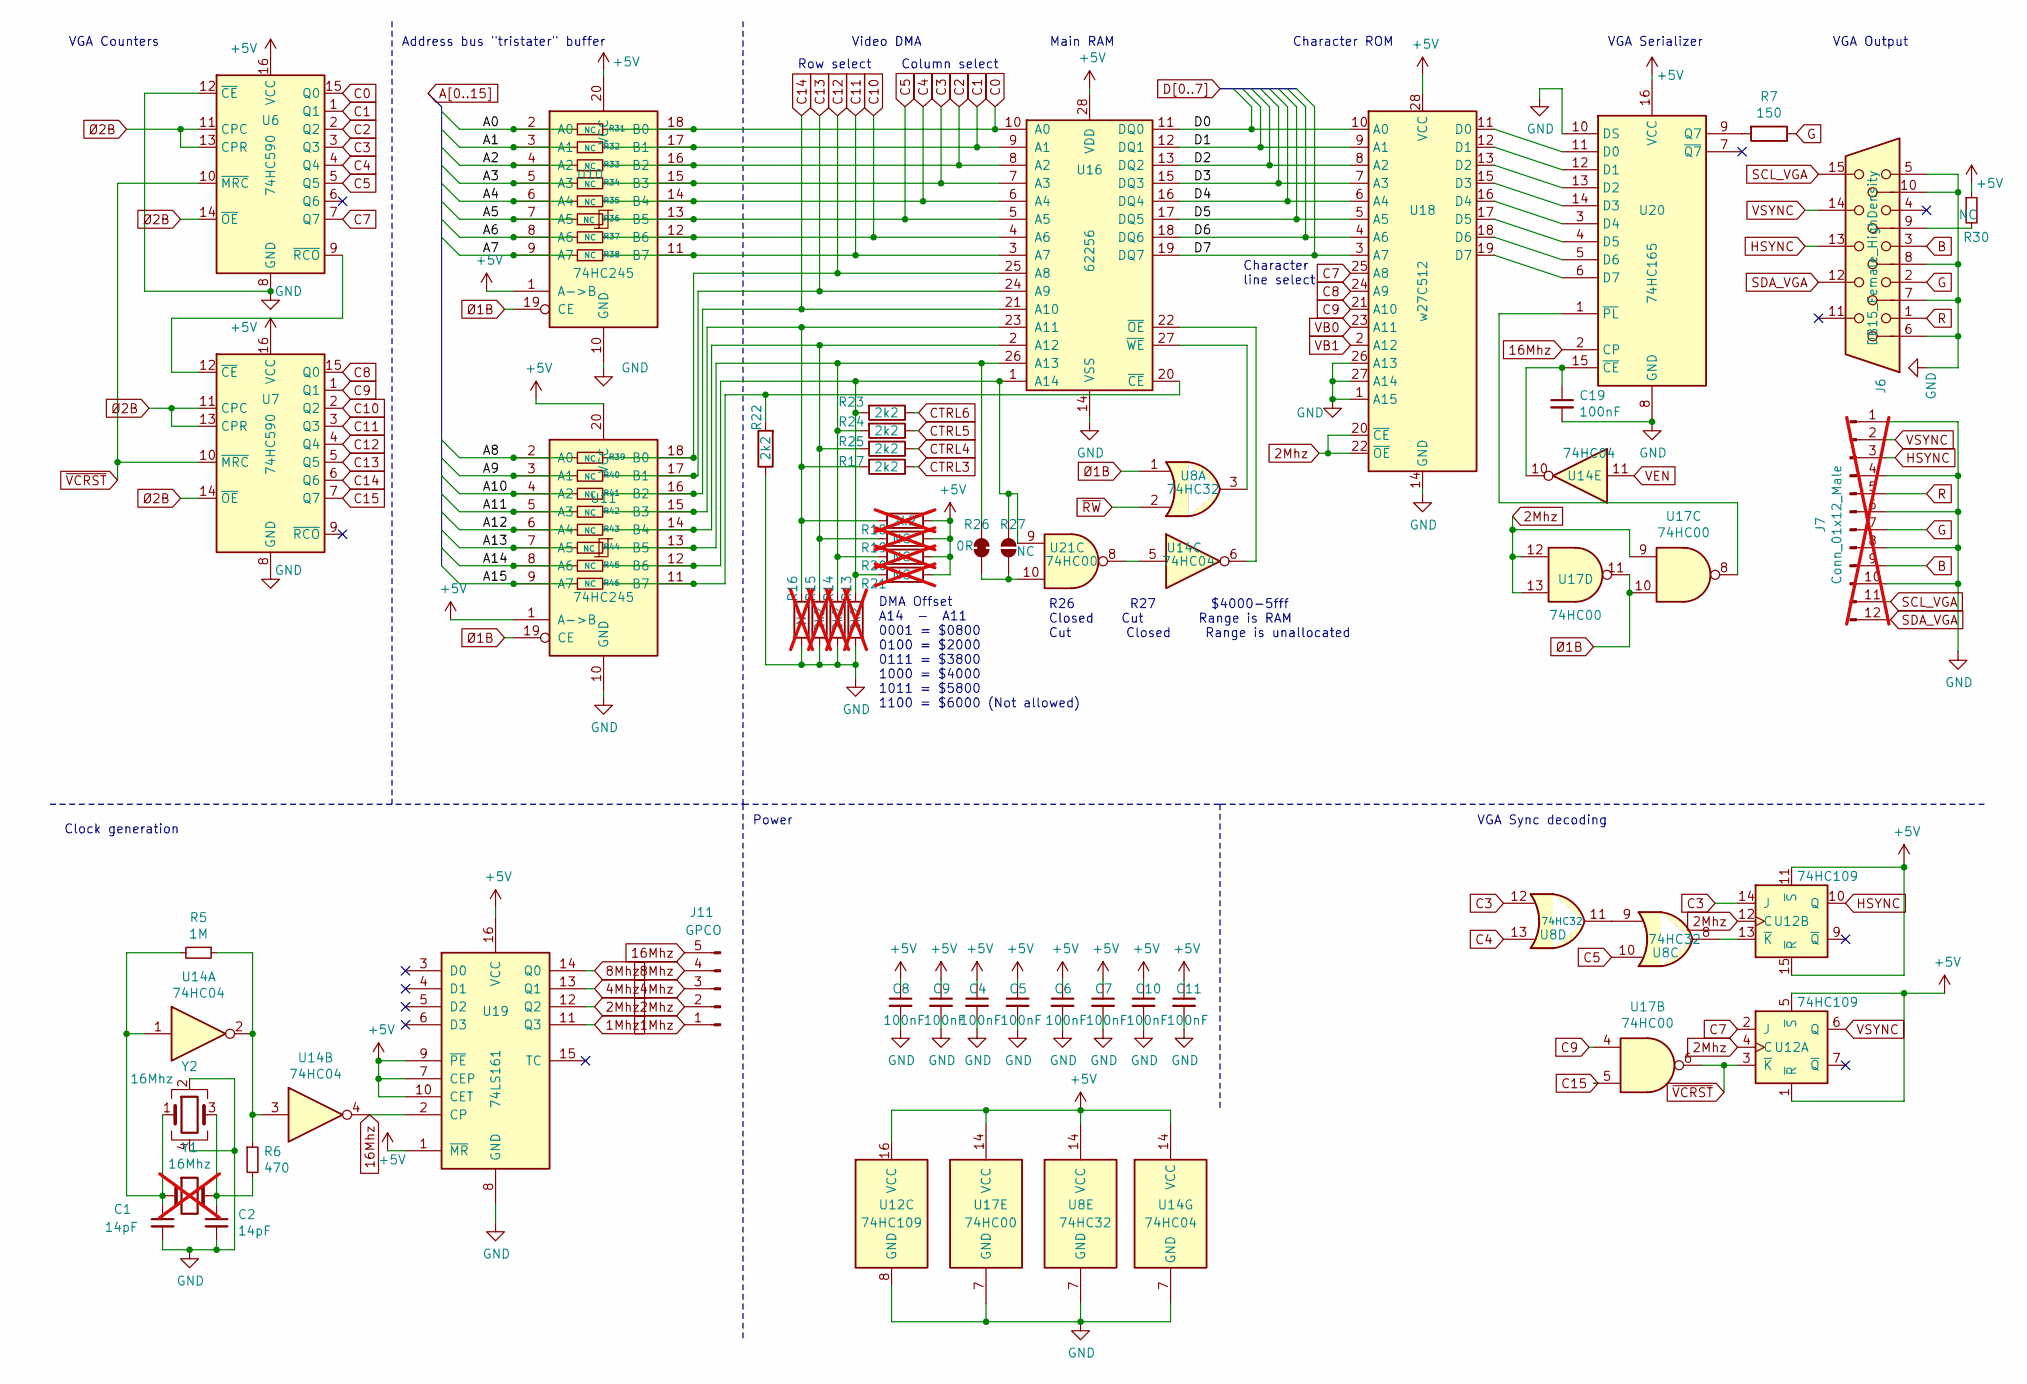
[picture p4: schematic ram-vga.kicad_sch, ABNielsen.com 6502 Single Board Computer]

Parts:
C1, C2: 14pF; C_0805_2012Metric; LCSC C519919
C4, C5, C6, C7, C8, C9, C10, C11, C19: 100nF; C_0603_1608Metric; LCSC C14663
J6: DB15_Female_HighDensity; DSUB-15-HD_Female_Horizontal_P2.29x1.98mm_EdgePinOffset8.35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; LCSC C138387
J7: Conn_01x12_Male; PinHeader_1x12_P2.54mm_Vertical; not fitted
J11: GPCO; PinHeader_1x05_P2.54mm_Vertical
R5: 1M; R_0805_2012Metric; LCSC C17514
R6: 470; R_0805_2012Metric; LCSC C17710
R7: 150; R_0805_2012Metric; LCSC C17471
R13, R14, R15, R18: 2k2; R_0805_2012Metric; LCSC C114561; not fitted
R16, R19, R20, R21: NC; R_0805_2012Metric; not fitted
R17, R22, R23, R24, R25: 2k2; R_0805_2012Metric; LCSC C114561
R26: 0R; SolderJumper-2_P1.3mm_Bridged_RoundedPad1.0x1.5mm
R27, R30, R31, R32, R33, R34, R35, R36, R37, R38, R39, R40, R41, R42, R43, R44, R45, R46: NC; SolderJumper-2_P1.3mm_Open_RoundedPad1.0x1.5mm
U6, U7: 74HC590; DIP-16_W7.62mm; LCSC C72115
U8: 74HC32; DIP-14_W7.62mm; LCSC C2325
U10, U11: 74HC245; DIP-20_W7.62mm; LCSC C72118
U12: 74HC109; DIP-16_W7.62mm; LCSC C72115
U14: 74HC04; DIP-14_W7.62mm; LCSC C2325
U16: 62256; DIP-28_W15.24mm; LCSC C72121
U17, U21: 74HC00; DIP-14_W7.62mm; LCSC C2325
U18: w27C512; DIP-28_W15.24mm; LCSC C72121
U19: 74LS161; DIP-16_W7.62mm; LCSC C72115
U20: 74HC165; DIP-16_W7.62mm; LCSC C72115
Y1: 16Mhz; Crystal_HC49-U_Vertical; not fitted
Y2: 16Mhz; Crystal_SMD_3225-4Pin_3.2x2.5mm; LCSC C13738

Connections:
1Mhz: J11.1, U19.11 (Q3)
2Mhz: J11.2, U6.11 (CPC), U6.13 (CPR), U6.14 (~OE), U7.11 (CPC), U7.13 (CPR), U7.14 (~OE), U12.4 (C), U12.12 (C), U17.9, U17.12, U17.13, U18.20 (~CE), U18.22 (~OE), U19.12 (Q2); also elsewhere on the board
4Mhz: J11.3, U19.13 (Q1)
8Mhz: J11.4, U19.14 (Q0)
16Mhz: J11.5, U14.4, U19.2 (CP), U20.2 (CP)
+5V: C4.1, C5.1, C6.1, C7.1, C8.1, C9.1, C10.1, C11.1, R18.1, R19.1, R20.1, R21.1, R30.1, U6.16 (VCC), U7.16 (VCC), U8.14 (VCC), U10.1 (A->B), U10.20 (VCC), U11.1 (A->B), U11.20 (VCC), U12.1 (~R), U12.5 (~S), U12.11 (~S), U12.15 (~R), U12.16 (VCC), U14.14 (VCC), U16.28 (VDD), U17.14 (VCC), U18.28 (VCC), U19.1 (~MR), U19.7 (CEP), U19.9 (~PE), U19.10 (CET), U19.16 (VCC), U20.16 (VCC); also elsewhere on the board
A0: R31.1, U10.2 (A0); also elsewhere on the board
A1: R32.1, U10.3 (A1); also elsewhere on the board
A2: R33.1, U10.4 (A2); also elsewhere on the board
A3: R34.1, U10.5 (A3); also elsewhere on the board
A4: R35.1, U10.6 (A4); also elsewhere on the board
A5: R36.1, U10.7 (A5); also elsewhere on the board
A6: R37.1, U10.8 (A6); also elsewhere on the board
A7: R38.1, U10.9 (A7); also elsewhere on the board
A8: R39.1, U11.2 (A0); also elsewhere on the board
A9: R40.1, U11.3 (A1); also elsewhere on the board
A10: R41.1, U11.4 (A2); also elsewhere on the board
A11: R42.1, U11.5 (A3); also elsewhere on the board
A12: R43.1, U11.6 (A4); also elsewhere on the board
A13: R44.1, U11.7 (A5); also elsewhere on the board
A14: R45.1, U11.8 (A6); also elsewhere on the board
A15: R46.1, U11.9 (A7); also elsewhere on the board
B: J6.3, J7.9
C0: R31.2, U6.15 (Q0), U10.18 (B0), U16.10 (A0)
C1: R32.2, U6.1 (Q1), U10.17 (B1), U16.9 (A1)
C2: R33.2, U6.2 (Q2), U10.16 (B2), U16.8 (A2)
C3: R34.2, U6.3 (Q3), U8.12, U10.15 (B3), U12.14 (J), U16.7 (A3)
C4: R35.2, U6.4 (Q4), U8.13, U10.14 (B4), U16.6 (A4)
C5: R36.2, U6.5 (Q5), U8.10, U10.13 (B5), U16.5 (A5)
C7: U6.7 (Q7), U12.2 (J), U18.25 (A8)
C8: U7.15 (Q0), U18.24 (A9)
C9: U7.1 (Q1), U17.4, U18.21 (A10)
C10: R37.2, U7.2 (Q2), U10.12 (B6), U16.4 (A6)
C11: R38.2, U7.3 (Q3), U10.11 (B7), U16.3 (A7)
C12: R39.2, U7.4 (Q4), U11.18 (B0), U16.25 (A8)
C13: R40.2, U7.5 (Q5), U11.17 (B1), U16.24 (A9)
C14: R41.2, U7.6 (Q6), U11.16 (B2), U16.21 (A10)
C15: U7.7 (Q7), U17.5
CTRL3: R17.1; also elsewhere on the board
CTRL4: R25.1; also elsewhere on the board
CTRL5: R24.1; also elsewhere on the board
CTRL6: R23.1; also elsewhere on the board
D0: U16.11 (DQ0), U18.10 (A0); also elsewhere on the board
D1: U16.12 (DQ1), U18.9 (A1); also elsewhere on the board
D2: U16.13 (DQ2), U18.8 (A2); also elsewhere on the board
D3: U16.15 (DQ3), U18.7 (A3); also elsewhere on the board
D4: U16.16 (DQ4), U18.6 (A4); also elsewhere on the board
D5: U16.17 (DQ5), U18.5 (A5); also elsewhere on the board
D6: U16.18 (DQ6), U18.4 (A6); also elsewhere on the board
D7: U16.19 (DQ7), U18.3 (A7); also elsewhere on the board
G: J6.2, J7.7, R7.1
GND: C1.2, C2.2, C4.2, C5.2, C6.2, C7.2, C8.2, C9.2, C10.2, C11.2, C19.2, J6.5, J6.6, J6.7, J6.8, J6.10, J7.1, J7.4, J7.6, J7.8, J7.10, R13.1, R14.1, R15.1, R16.1, R22.1, U6.8 (GND), U6.12 (~CE), U7.8 (GND), U8.7 (GND), U10.10 (GND), U11.10 (GND), U12.8 (GND), U14.7 (GND), U16.14 (VSS), U17.7 (GND), U18.1 (A15), U18.14 (GND), U18.26 (A13), U18.27 (A14), U19.8 (GND), U20.8 (GND), U20.10 (DS), Y2.2, Y2.4; also elsewhere on the board
HSYNC: J6.13, J7.3, U12.10 (Q)
unnamed: C1.1, R5.2, U14.1, Y1.1, Y2.1
unnamed: C2.1, R6.2, Y1.2, Y2.3
unnamed: J6.9, R30.2
unnamed: R5.1, R6.1, U14.2, U14.3
unnamed: R26.1 (A), R27.1 (A), U21.10
unnamed: R14.2, R20.2, R24.2, R26.2 (B), R44.2, U11.13 (B5), U16.26 (A13)
unnamed: R13.2, R21.2, R23.2, R27.2 (B), R45.2, U11.12 (B6), U16.1 (A14), U21.9
unnamed: U6.9 (~RCO), U7.12 (~CE)
unnamed: U8.9, U8.11
unnamed: R16.2, R17.2, R18.2, R42.2, U11.15 (B3), U16.23 (A11)
unnamed: R15.2, R19.2, R25.2, R43.2, U11.14 (B4), U16.2 (A12)
unnamed: R22.2, R46.2, U11.11 (B7), U16.20 (~CE)
unnamed: U8.8, U12.13 (~K)
unnamed: U14.5, U21.8
unnamed: U14.6, U16.22 (~OE)
unnamed: U8.3, U16.27 (~WE)
unnamed: U18.11 (D0), U20.11 (D0)
unnamed: U18.12 (D1), U20.12 (D1)
unnamed: U18.13 (D2), U20.13 (D2)
unnamed: U18.15 (D3), U20.14 (D3)
unnamed: U18.16 (D4), U20.3 (D4)
unnamed: U18.17 (D5), U20.4 (D5)
unnamed: U18.18 (D6), U20.5 (D6)
unnamed: U18.19 (D7), U20.6 (D7)
unnamed: R7.2, U20.9 (Q7)
unnamed: C19.1, U14.10, U20.15 (~CE)
unnamed: U17.8, U20.1 (~PL)
R: J6.1, J7.5
SCL_VGA: J6.15, J7.11; also elsewhere on the board
SDA_VGA: J6.12, J7.12; also elsewhere on the board
VB0: U18.23 (A11); also elsewhere on the board
VB1: U18.2 (A12); also elsewhere on the board
VEN: U14.11; also elsewhere on the board
VSYNC: J6.14, J7.2, U12.6 (Q)
~RW: U8.2; also elsewhere on the board
~VCRST: U6.10 (~MRC), U7.10 (~MRC), U12.3 (~K), U17.6
Ø1B: U8.1, U10.19 (CE), U11.19 (CE), U17.10, U17.11; also elsewhere on the board

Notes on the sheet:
Row select
VGA Counters
VGA Sync decoding
DMA Offset A14 - A11 0001 = $0800 0100 = $2000 0111 = $3800 1000 = $4000 1011 = $5800 1100 = $6000 (Not allowed)
Address bus "tristater" buffer
Character ROM
VGA Output
Video DMA
VGA Serializer
R26 R27 $4000-5fff Closed Cut Range is RAM Cut Closed Range is unallocated
Character line select
Column select
Clock generation
Main RAM
Power

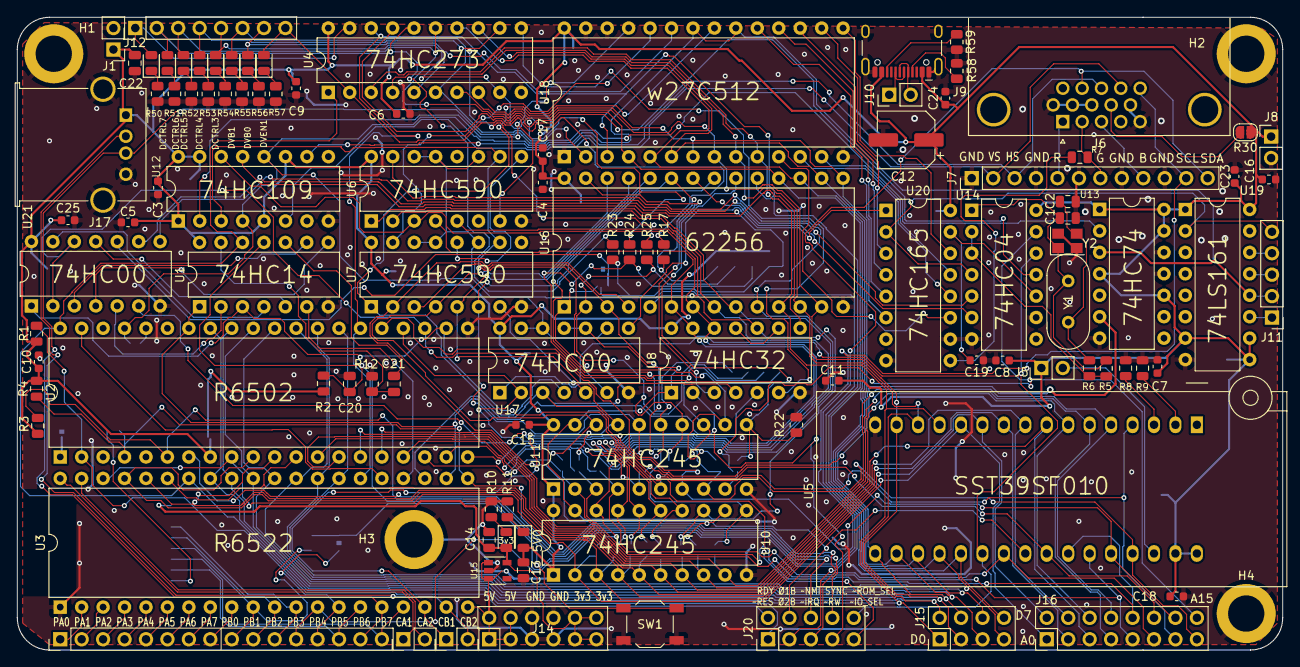
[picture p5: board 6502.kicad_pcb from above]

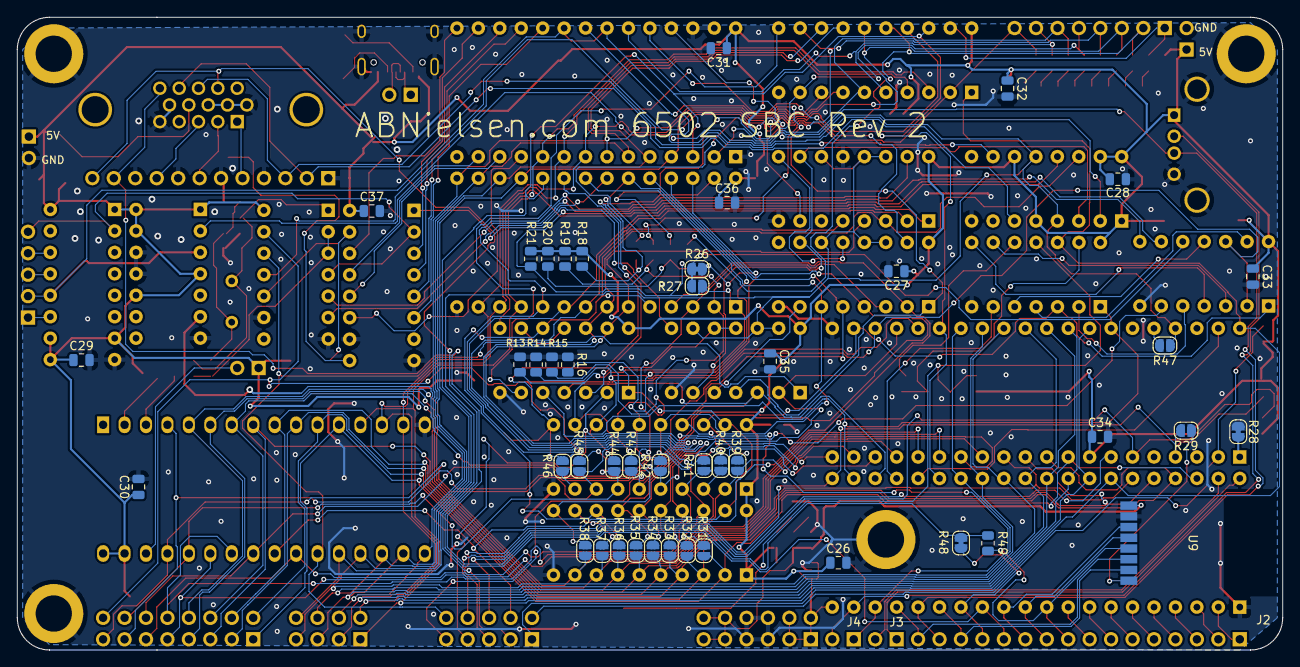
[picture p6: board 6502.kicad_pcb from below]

Board: 2 copper layers, 149.9 x 74.9 mm, 151 parts (44 on the bottom side), 150 nets.

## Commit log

2021-10-21 Correct license
    [6502.kicad_pcb, 6502.sch, ram-vga.sch]
2021-10-30 PCB Silkscreen annotations added
    [6502.kicad_pcb, 6502.sch, memmap.cfg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]
2021-10-30 New PCB PDF
2022-04-03 Wireless nRF24L01+ bootloader added! No more Padauk PMS171b!
    [6502.kicad_pcb, 6502.kicad_sch, 6502.sch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]
2022-04-12 Removed build output and .DS_Store files
    [6502.kicad_pcb, 6502.kicad_sch, 6502.sch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]
2022-04-12 Updated BOM.
    [6502.csv]
2022-05-27 PS/2 via shift register upgrade!
    [6502.kicad_pcb, 6502.kicad_sch, ram-vga.kicad_sch]
2022-07-21 Tape interface upgrade - still missing housekeeping bits
    [6502.csv, 6502.kicad_sch, memmap.cfg]
2022-09-18 BASIC interpreter support, PS/2 serial code, scrolling support, cleanup.
    [memmap.cfg]
2022-10-18 R1B2 gerbers, start+stop bits in modem driver
    [6502.kicad_pcb, 6502.kicad_sch, ram-vga.kicad_sch]
2022-11-06 Delete bom.txt
    Outdated - BOM can be found on the hackaday.io page and in the kicad files
2022-11-24 Solder jumpers instead of 0402 resistors, redundant 0805 decoupling caps
    [6502.kicad_sch, 6502.sch, ram-vga.kicad_sch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]
2025-02-27 Silkscreen indicators, updated BOM and gerbers and stuff
    [6502-top-position-fixed.csv, 6502.csv, 6502.kicad_sch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]
2025-07-06 Revision 2 published
    [6502-CuBottom.gbr, 6502-CuTop.gbr, 6502-EdgeCuts.gbr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]
